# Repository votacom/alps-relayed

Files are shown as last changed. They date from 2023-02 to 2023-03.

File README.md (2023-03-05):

# alps-relayed
Input selection circuit board replacing the Alps ASD-1025 and ASD-1017 motor switches (and possibly others) in Pioneer's A-50xR, A-550R and A-450R amplifiers (and possibly others), using fast relays. The switching circuit supports the amplifier's native remote control and is faster than the motor switch (typically 42 milliseconds on average).

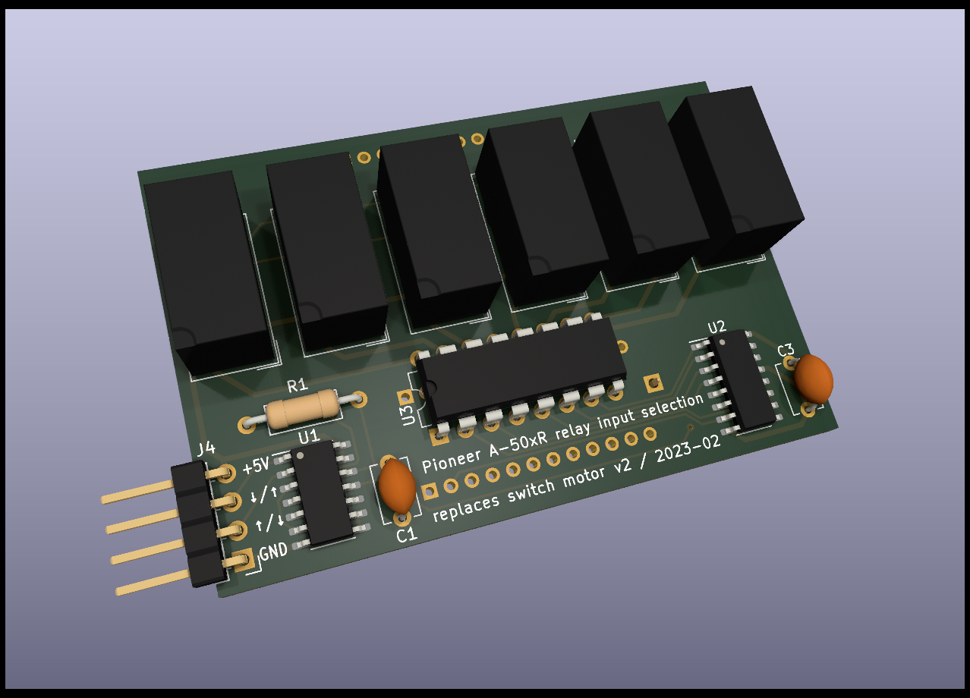
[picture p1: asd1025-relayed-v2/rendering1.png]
3D rendering of the circuit board version 2, top view

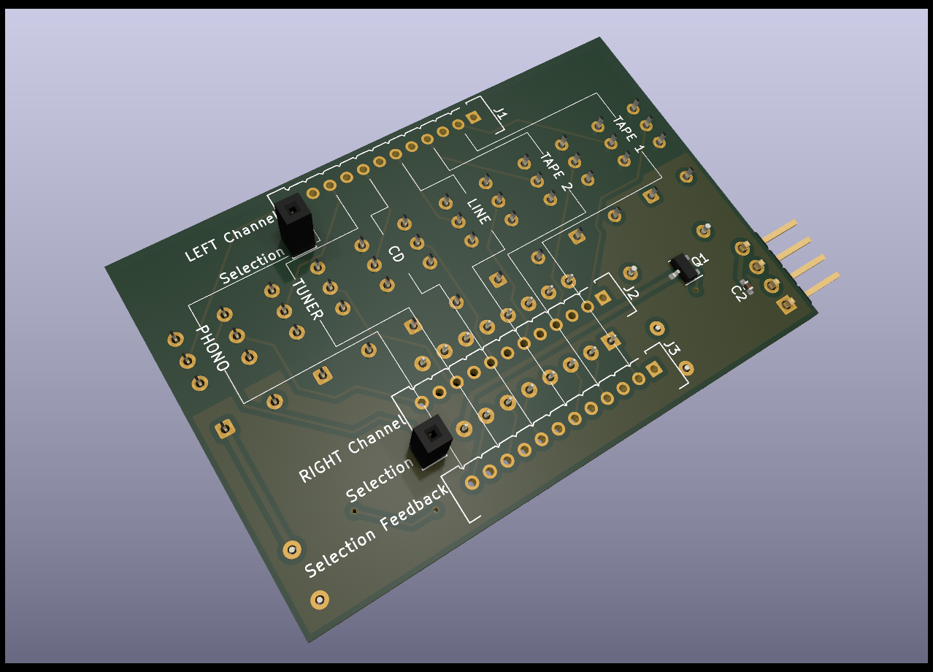
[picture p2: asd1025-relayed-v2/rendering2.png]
3D rendering of the circuit board version 2, bottom view


## Supported amplifiers
This circuit board is designed to replace ASD-1025 in the Pioneer A-502R, A-502R-G, A-503R, and A-503R-G amplifier models. It can also replace ASD-1017 in the Pioneer A-501R, A-550R and A-450R models, though with the downside of the "Source" recording input selection not working anymore (unless four jumpers are added, but then tape looping becomes possible, which is inhibited by ASD-1017). Since the ASD-1025 was also used in A-602R, it may be possible to use it in this model as well, but this has not been verified.

## Versions
There are two versions of the replacement board: v1 and v2.
v1 is larger, connects to the motor pin holes via individual connectors, and includes a direct plug connector to the motor driver IC pin holes and an additional stabilizing blind plug connector. Its layout is only applicable to the A-502R and A-503R models.
v2 is more compact, uses only three broad connectors to the motor pin holes, and does not directly plug into the motor driver IC pin holes, but uses a patch wire connector instead. This way, it can also be used in the A-501R, A-550R and A-450R models.
The two versions also slightly differ in their circuitry.

## Installation in Pioneer A-502R / A-503R

### v1 Installation
To install the v1 replacement board,
1. uninstall (unsolder) from the amplifier's input assembly board
   - the switch motor,
   - the motor driver IC (TA7291S), and
   - the nearby tall electrolytic capacitor (labelled C293),
2. solder simple vertical pin headers (e.g. Samtek TSW-1xx) into the input assembly board as follows:
   - a single-row 9-pin header strip where the motor driver IC was,
   - a single pin in each of the now-free motor's drill holes that would be connected by the replacement board (20 in total), and
   - a single pin in the free drill hole that would be connected by the replacement board's single corner socket, right next to the ribbon cable socket,
3. plug the replacement board on the input assembly board, aligning the selection board's new pins with the replacement board's sockets.

### v2 Installation
To install the v2 replacement board,
1. uninstall (unsolder) from the amplifier's input assembly board
   - the switch motor, and
   - the motor driver IC (TA7291S),
2. solder a single-row 9-pin header strip (e.g. Samtek TSW-1xx) to replace the motor driver IC,
3. from three Hirose DF3A-12P-2DSA pin headers, clip off every other pin (the odd-numbered pins) and solder them into the upper rows of the three double-row motor drill holes (pay attention to orientation),
4. stick a plain pin (min. 7mm) in each of the replacement board's two "Selection" sockets,
5. plug the replacement board on the input assembly board (the two plain pins extending from the replacement board should go through pin holes the on input assembly board),
6. use four individual jumper wires to connect the replacement board's +5V, GND, ↑, and ↓ pins to four of the motor driver IC's replacement header strip's pins (counted from left to right, starting at 1) as follows:
   - +5V connects to pin number 4,
   - GND connects to pin number 5,
   - ↑ and ↓ connect to pins number 1 and 9 in any order.

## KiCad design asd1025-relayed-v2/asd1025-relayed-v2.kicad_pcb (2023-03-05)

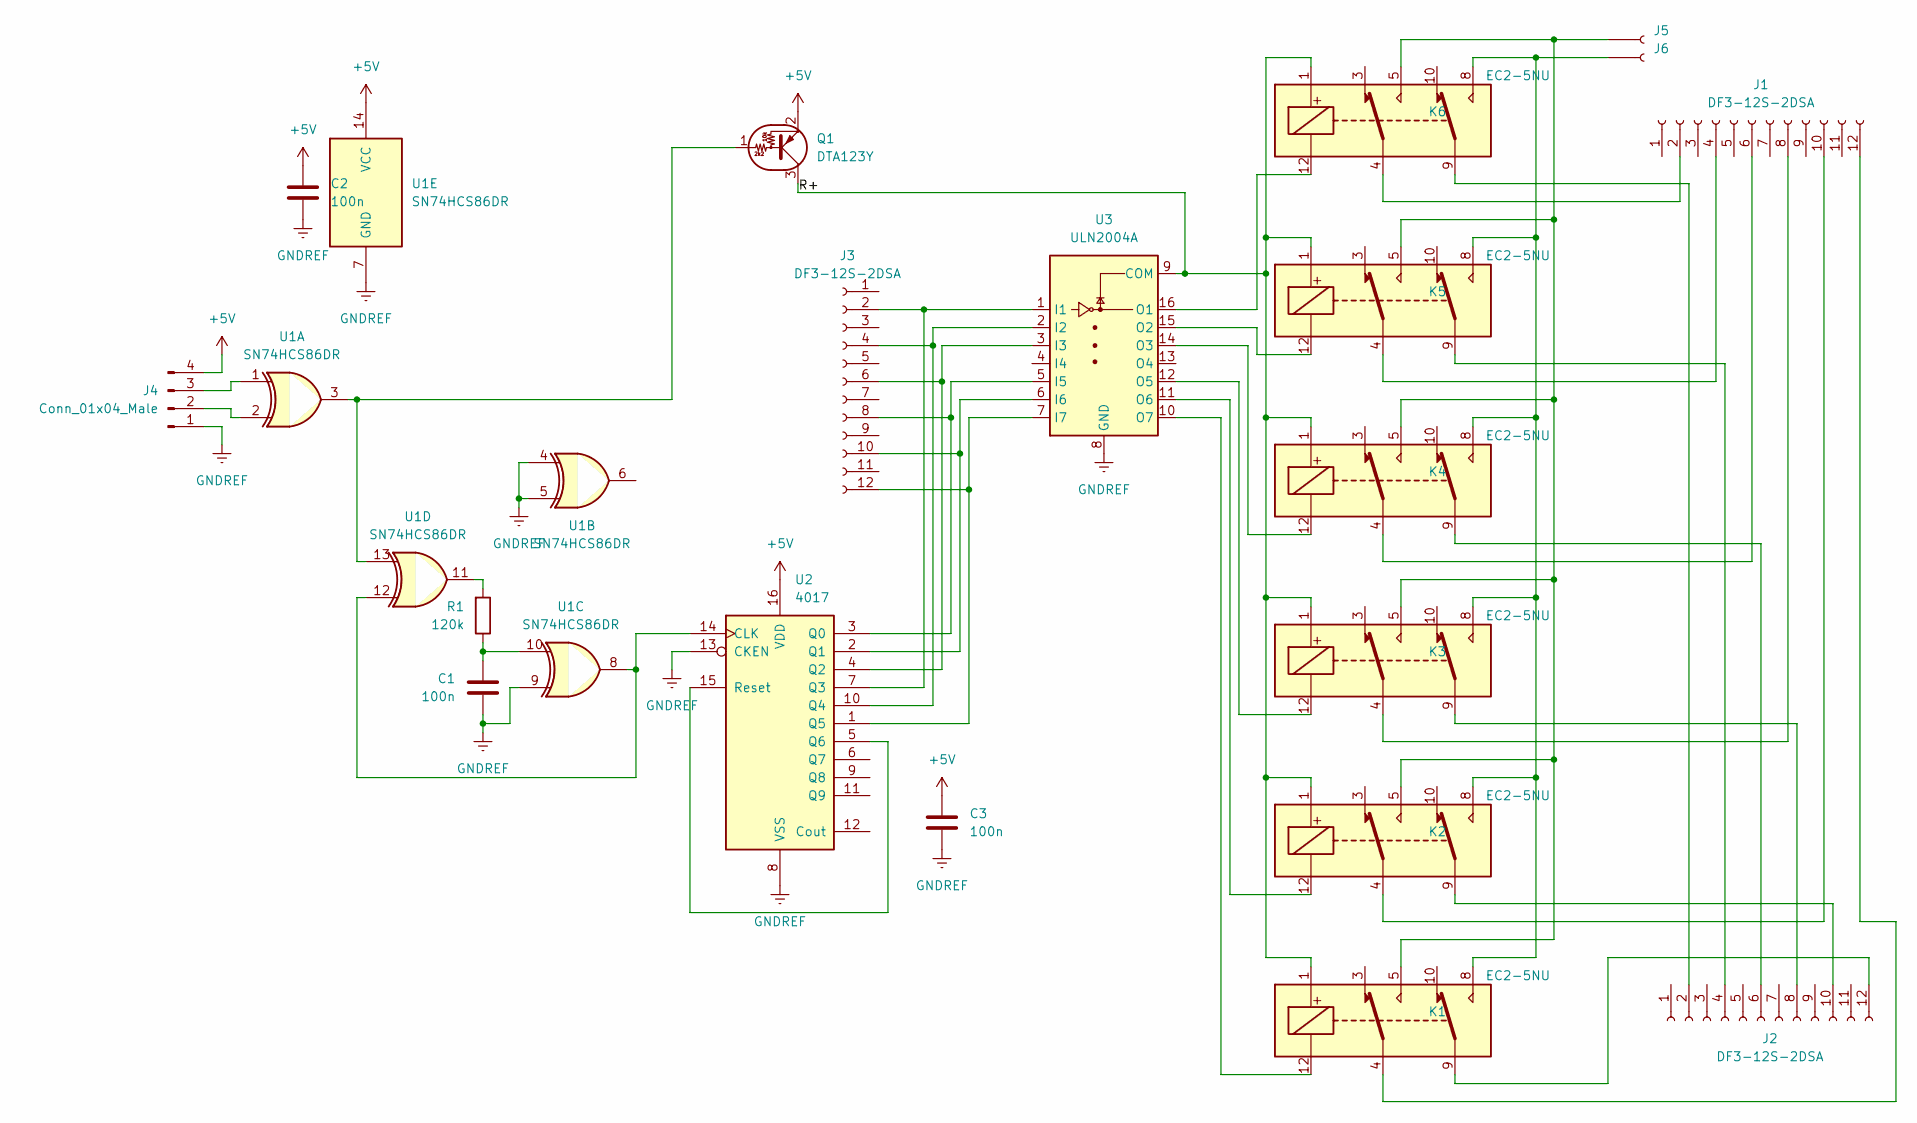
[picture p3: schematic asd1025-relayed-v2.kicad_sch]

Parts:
C1, C3: 100n; C_Disc_D5.1mm_W3.2mm_P5.00mm
C2: 100n; C_0402_1005Metric_Pad0.74x0.62mm_HandSolder
J1, J2, J3: DF3-12S-2DSA; Hirose_DF3-12S-2DSA_1x12_P2.00mm_Vertical
J4: Conn_01x04_Male; PinHeader_1x04_P2.54mm_Horizontal
J5, J6: Conn_01x01_Female; PinSocket_1x01_P2.54mm_Vertical
K1, K2, K3, K4, K5, K6: EC2-5NU; Relay_DPDT_Kemet_EC2
Q1: DTA123Y; SOT-23
R1: 120k; R_Axial_DIN0207_L6.3mm_D2.5mm_P10.16mm_Horizontal
U1: SN74HCS86DR; SOIC-14_3.9x8.7mm_P1.27mm
U2: 4017; SOIC-16_3.9x9.9mm_P1.27mm
U3: ULN2004A; DIP-16_W7.62mm

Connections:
+5V: C2.1, C3.1, J4.4, Q1.2 (E), U1.14 (VCC), U2.16 (VDD)
/R+: K1.1, K2.1, K3.1, K4.1, K5.1, K6.1, Q1.3 (C), U3.9 (COM)
GNDREF: C1.1, C2.2, C3.2, J4.1, U1.4, U1.5, U1.7 (GND), U1.9, U2.8 (VSS), U2.13 (CKEN), U3.8 (GND)
unnamed: C1.2, R1.1, U1.10
unnamed: J1.2, K6.4
unnamed: J1.4, K5.4
unnamed: J1.6, K4.4
unnamed: J1.8, K3.4
unnamed: J1.10, K2.4
unnamed: J1.12, K1.4
unnamed: J2.2, K6.9
unnamed: J2.4, K5.9
unnamed: J2.6, K4.9
unnamed: J2.8, K3.9
unnamed: J2.10, K2.9
unnamed: J2.12, K1.9
unnamed: J3.2, U2.7 (Q3), U3.1 (I1)
unnamed: J3.4, U2.10 (Q4), U3.2 (I2)
unnamed: J3.6, U2.4 (Q2), U3.3 (I3)
unnamed: J3.8, U2.3 (Q0), U3.5 (I5)
unnamed: J3.10, U2.2 (Q1), U3.6 (I6)
unnamed: J3.12, U2.1 (Q5), U3.7 (I7)
unnamed: J4.2, U1.2
unnamed: J4.3, U1.1
unnamed: J5.1, K1.5, K2.5, K3.5, K4.5, K5.5, K6.5
unnamed: J6.1, K1.8, K2.8, K3.8, K4.8, K5.8, K6.8
unnamed: K1.12, U3.10 (O7)
unnamed: K2.12, U3.11 (O6)
unnamed: K3.12, U3.12 (O5)
unnamed: K4.12, U3.14 (O3)
unnamed: K5.12, U3.15 (O2)
unnamed: K6.12, U3.16 (O1)
unnamed: R1.2, U1.11
unnamed: Q1.1 (B), U1.3, U1.13
unnamed: U1.8, U1.12, U2.14 (CLK)
unnamed: U2.5 (Q6), U2.15 (Reset)

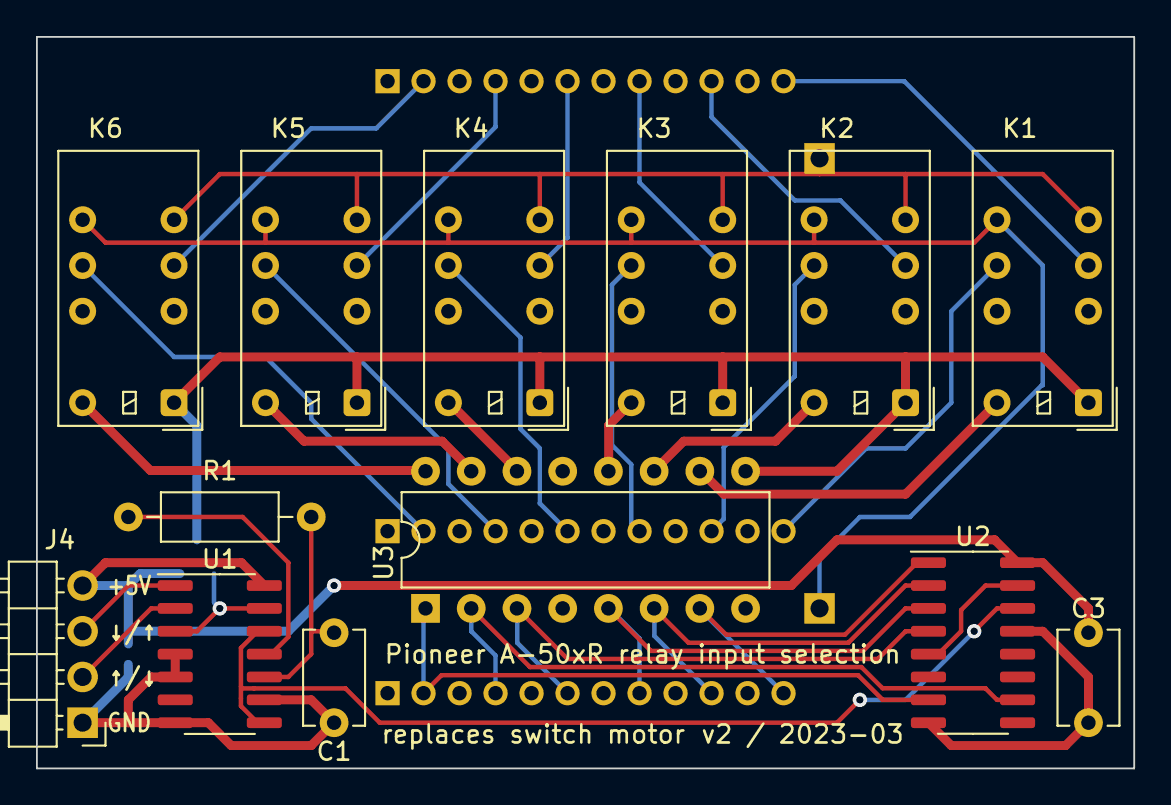
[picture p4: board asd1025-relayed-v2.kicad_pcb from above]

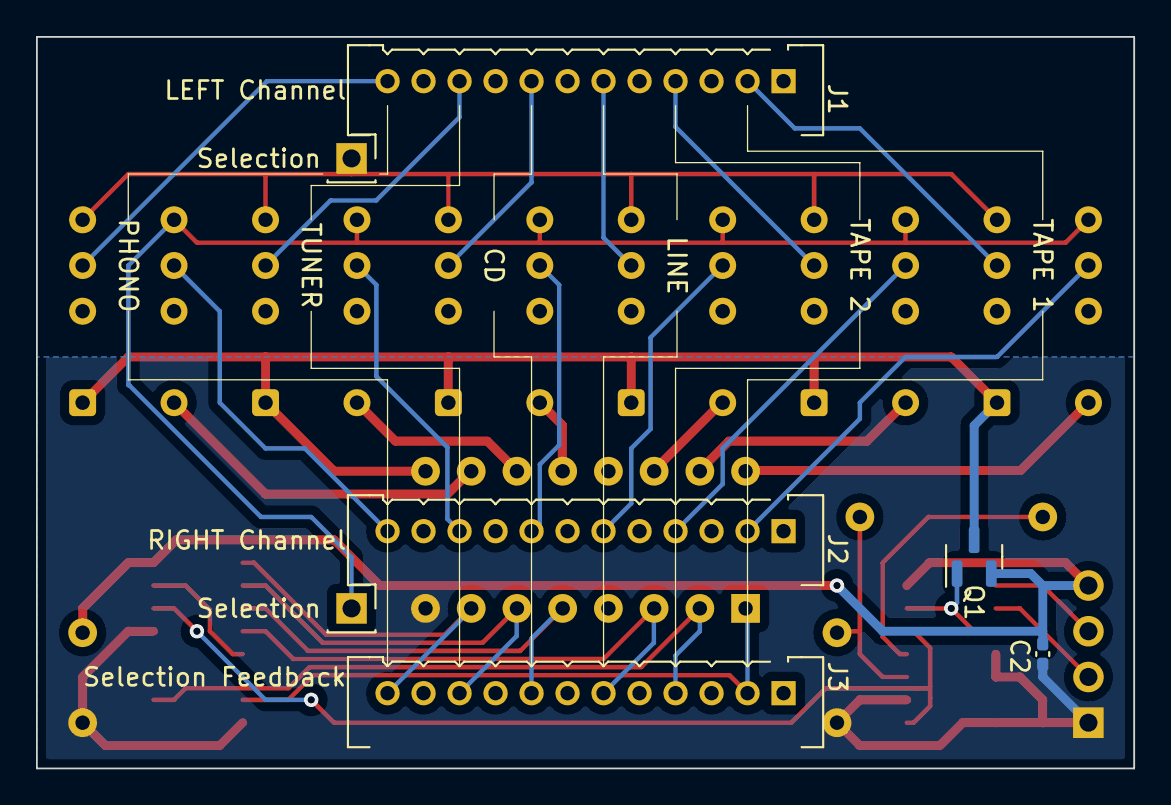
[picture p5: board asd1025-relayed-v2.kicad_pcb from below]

Board: 2 copper layers, 61.0 x 40.6 mm, 20 parts (7 on the bottom side), 36 nets.

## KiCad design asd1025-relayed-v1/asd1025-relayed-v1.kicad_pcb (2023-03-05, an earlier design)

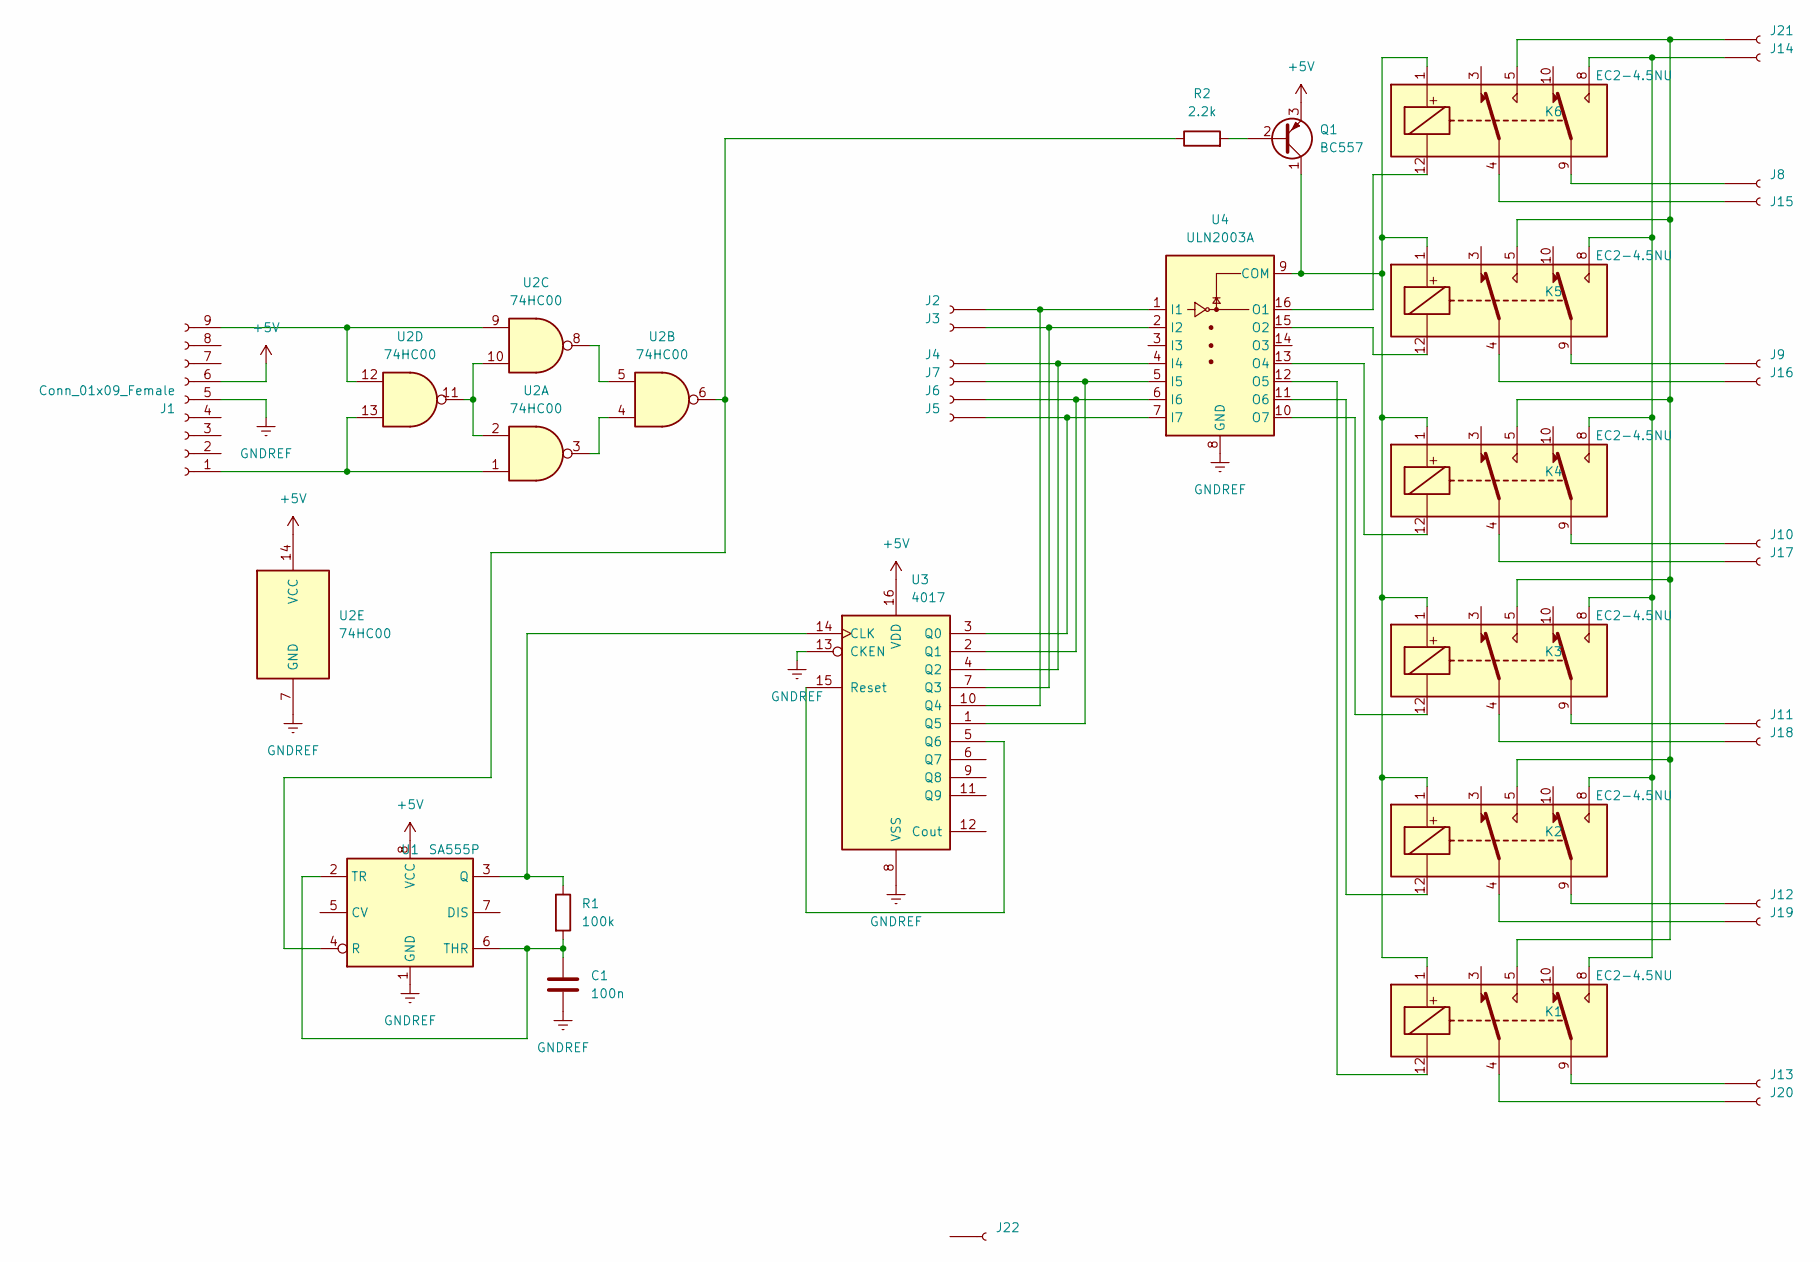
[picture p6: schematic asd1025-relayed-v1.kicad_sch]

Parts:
C1: 100n; C_Disc_D5.1mm_W3.2mm_P5.00mm
J1: Conn_01x09_Female; PinSocket_1x09_P2.54mm_Vertical
J2, J3, J4, J5, J6, J7, J8, J9, J10, J11, J12, J13, J14, J15, J16, J17, J18, J19, J20, J21, J22: Conn_01x01_Female; PinSocket_1x01_P2.54mm_Vertical
K1, K2, K3, K4, K5, K6: EC2-4.5NU; Relay_DPDT_Kemet_EC2
Q1: BC557; TO-92_Inline_Wide
R1: 100k; R_Axial_DIN0207_L6.3mm_D2.5mm_P10.16mm_Horizontal
R2: 2.2k; R_Axial_DIN0207_L6.3mm_D2.5mm_P10.16mm_Horizontal
U1: SA555P; DIP-8_W7.62mm
U2: 74HC00; DIP-14_W7.62mm
U3: 4017; DIP-16_W7.62mm
U4: ULN2003A; DIP-16_W7.62mm

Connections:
+5V: J1.6, Q1.3 (E), U1.8 (VCC), U2.14 (VCC), U3.16 (VDD)
GNDREF: C1.2, J1.5, U1.1 (GND), U2.7 (GND), U3.8 (VSS), U3.13 (CKEN), U4.8 (GND)
unnamed: C1.1, R1.2, U1.2 (TR), U1.6 (THR)
unnamed: J1.1, U2.1, U2.13
unnamed: J2.1, U3.10 (Q4), U4.1 (I1)
unnamed: J3.1, U3.7 (Q3), U4.2 (I2)
unnamed: J4.1, U3.4 (Q2), U4.4 (I4)
unnamed: J5.1, U3.3 (Q0), U4.7 (I7)
unnamed: J6.1, U3.2 (Q1), U4.6 (I6)
unnamed: J7.1, U3.1 (Q5), U4.5 (I5)
unnamed: J8.1, K6.9
unnamed: J9.1, K5.9
unnamed: J10.1, K4.9
unnamed: J11.1, K3.9
unnamed: J12.1, K2.9
unnamed: J13.1, K1.9
unnamed: J14.1, K1.8, K2.8, K3.8, K4.8, K5.8, K6.8
unnamed: J15.1, K6.4
unnamed: J16.1, K5.4
unnamed: J17.1, K4.4
unnamed: J18.1, K3.4
unnamed: J19.1, K2.4
unnamed: J20.1, K1.4
unnamed: J21.1, K1.5, K2.5, K3.5, K4.5, K5.5, K6.5
unnamed: K1.1, K2.1, K3.1, K4.1, K5.1, K6.1, Q1.1 (C), U4.9 (COM)
unnamed: K1.12, U4.12 (O5)
unnamed: K2.12, U4.11 (O6)
unnamed: K3.12, U4.10 (O7)
unnamed: K4.12, U4.13 (O4)
unnamed: K5.12, U4.15 (O2)
unnamed: K6.12, U4.16 (O1)
unnamed: Q1.2 (B), R2.2
unnamed: R1.1, U1.3 (Q), U3.14 (CLK)
unnamed: R2.1, U1.4 (R), U2.6
unnamed: U2.3, U2.4
unnamed: U2.5, U2.8
unnamed: J1.9, U2.9, U2.12
unnamed: U2.2, U2.10, U2.11
unnamed: U3.5 (Q6), U3.15 (Reset)

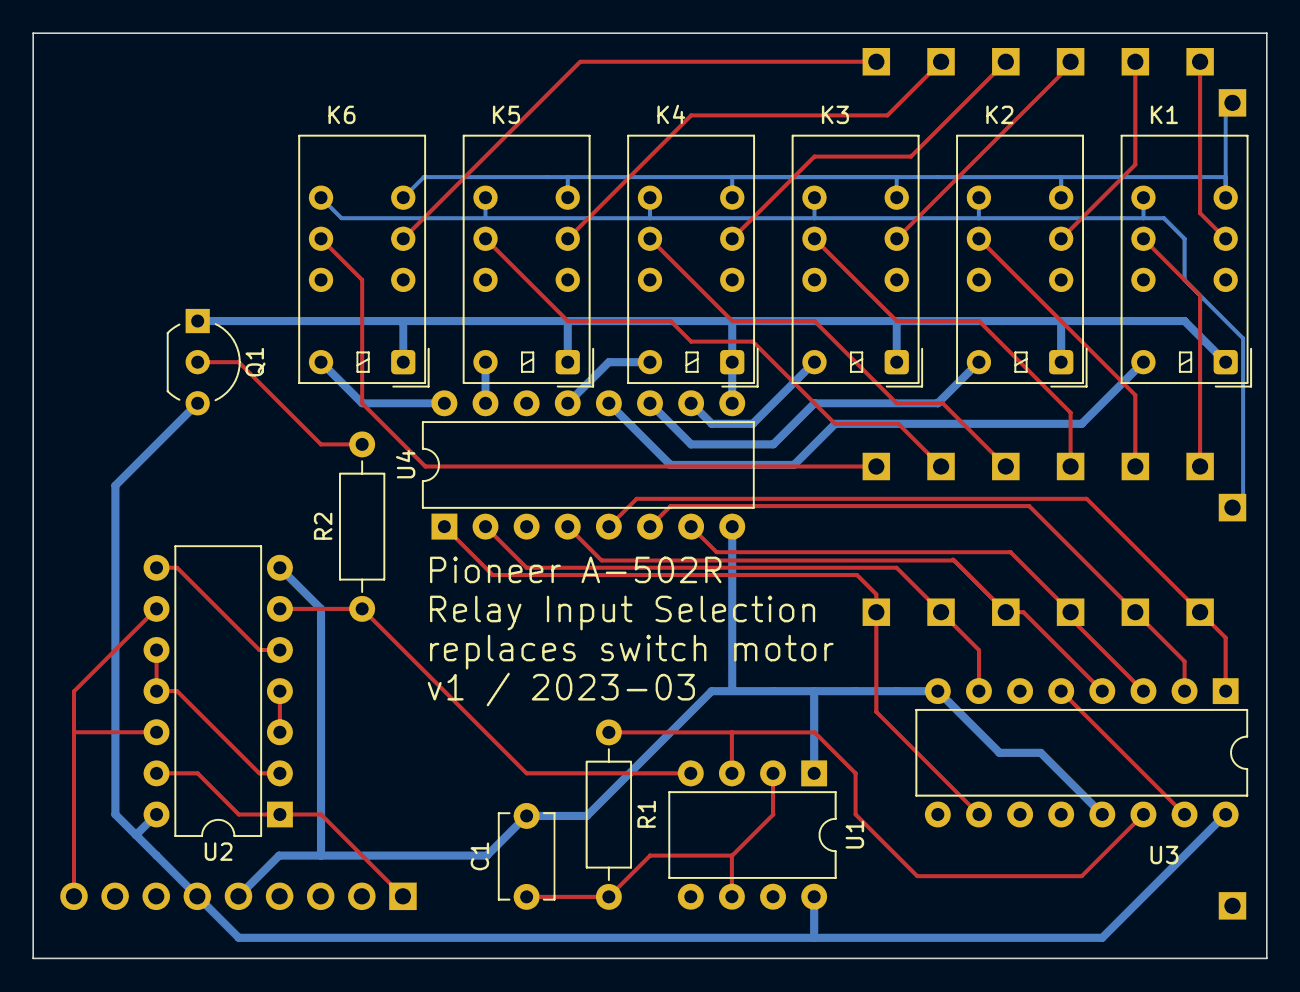
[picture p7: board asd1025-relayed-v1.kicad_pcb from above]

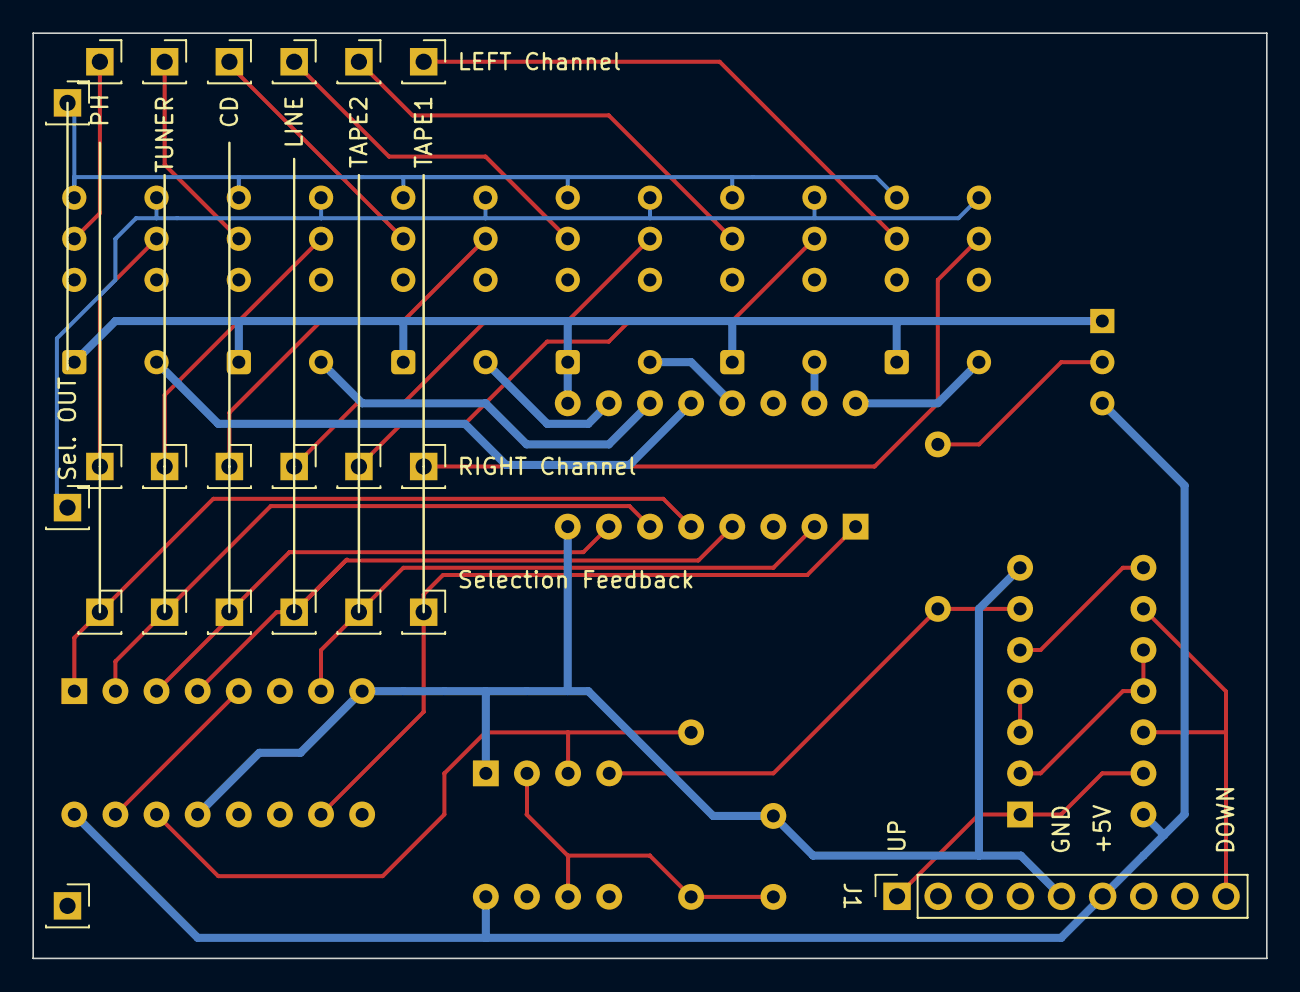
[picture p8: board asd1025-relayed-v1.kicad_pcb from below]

Board: 2 copper layers, 76.2 x 57.2 mm, 36 parts (22 on the bottom side), 39 nets.

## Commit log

2023-02-23 Initial population of the repository with KiCad files
    [asd1025-relayed.kicad_pcb, asd1025-relayed.kicad_sch]
2023-02-23 add 3D rendering picture of the bottom of the board
2023-02-25 add v2 design
    [asd1025-relayed-v2.kicad_pcb, asd1025-relayed-v2.kicad_sch, asd1025-relayed.kicad_pcb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]
2023-02-25 remove duplicate files
    [asd1025-relayed.kicad_pcb, asd1025-relayed.kicad_sch]
2023-02-25 rename first project to -v1
    [asd1025-relayed-v1.kicad_pcb, asd1025-relayed-v1.kicad_sch]
2023-02-26 fix mistake in v2 board about oscillator timing logic, nicer bottom silkscreen, no clock enabled signal needed anymore
    [asd1025-relayed-v2.kicad_pcb, asd1025-relayed-v2.kicad_sch]
2023-02-27 change oscillator frequency to minimum to ensure 10ms between relai cut-off and on-switching
    [asd1025-relayed-v2.kicad_pcb, asd1025-relayed-v2.kicad_sch]
2023-02-27 Update README.md
    Generalize README to support possible other ALPS motors and amps.
2023-03-05 fix v1: relays would switch by passing current through base-emittor-resistors in darlington array even if main transistor Q1 is off
    [asd1025-relayed-v1.kicad_pcb, asd1025-relayed-v1.kicad_sch]
2023-03-05 fix v2: relays would switch by passing current through base-emittor-resistors in darlington array even if main transistor Q1 is off
    [asd1025-relayed-v2.kicad_pcb, asd1025-relayed-v2.kicad_sch]
